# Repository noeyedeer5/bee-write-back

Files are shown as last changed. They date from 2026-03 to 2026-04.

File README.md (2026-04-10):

# Bee Write Back

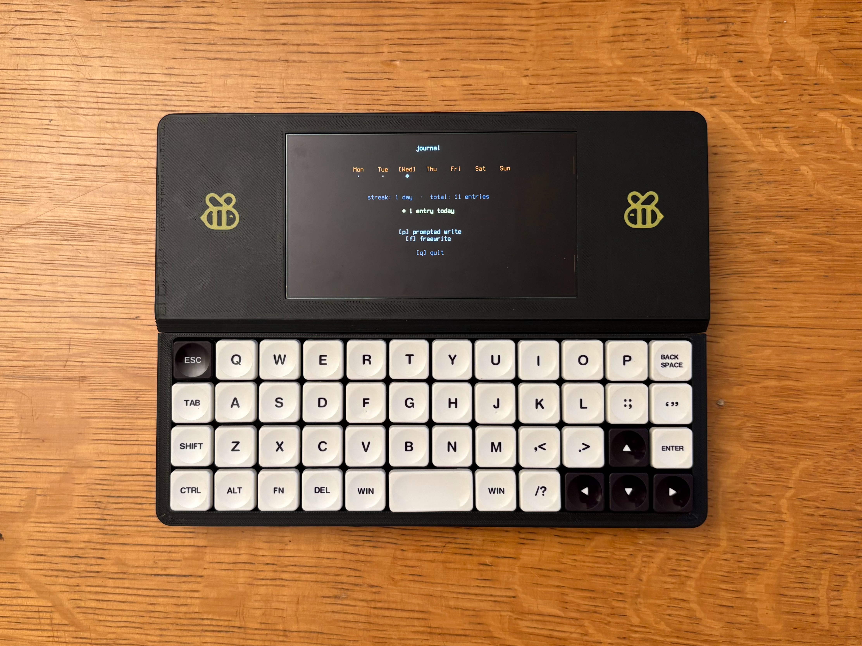
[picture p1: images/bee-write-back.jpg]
Bee Write Back WriterDeck


## Table of Contents

- [Introduction](#introduction)
- [Build Guide](#build-guide)
- [Hardware](#hardware)
- [Software](#software)
- [Cost](#cost)

## Introduction

I struggled to fall alseep easily for a while, and after being recommended journaling I found that it helped me immensely. The one catch was that I didn't like writing in a physical journal, since I would be greeted by all of my previous entries and all the emotions would come flooding back.

To solve this problem, I created a simple Raspberry Pi based journal, which I could use each night, entering in the chaos of the day, locking it away once I was done. After creating this, I found that the form factor of the writerdeck was really fun to use, and began developing more apps and functions, including a simple Claude chat client.

## Build Guide

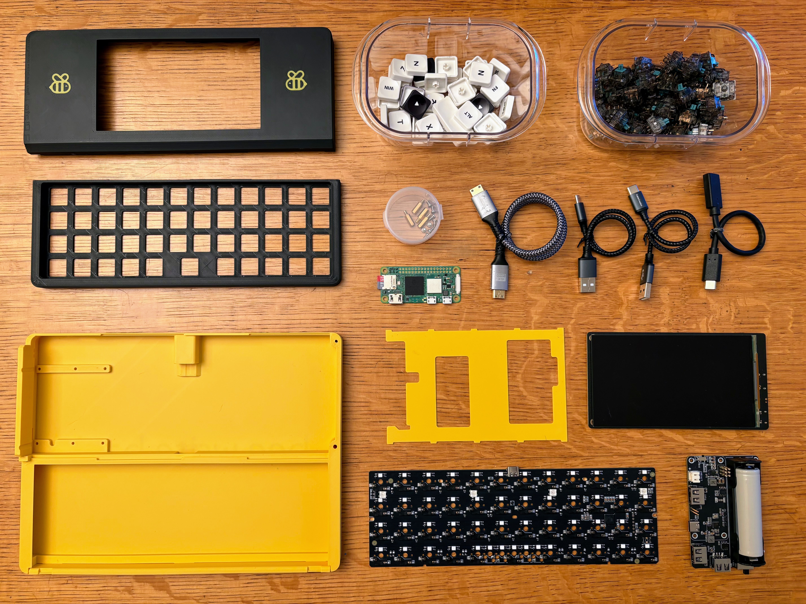
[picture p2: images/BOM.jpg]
Bee Write Back Components

  
You can view the PDF [here](Hardware/Bee%20Write%20Back%20Build%20Guide.pdf)  
Or the assembly video [here](https://youtu.be/JutsTp7yeNU)  
And when you're ready to print, check out the print profile [here](https://makerworld.com/en/models/2643352-bee-write-back-diy-writerdeck#profileId-2921008)  
  
P.S. if you're curious, try spinning around the 3D model [here](https://cad.onshape.com/documents/e6482d1ab00cb5a2719e37b7/w/38d6de8130338c05d74e4ecf/e/8865c15cb975933cc3691846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). Onshape is free, and I highly encourage taking a look at the model in 3D!

## Hardware

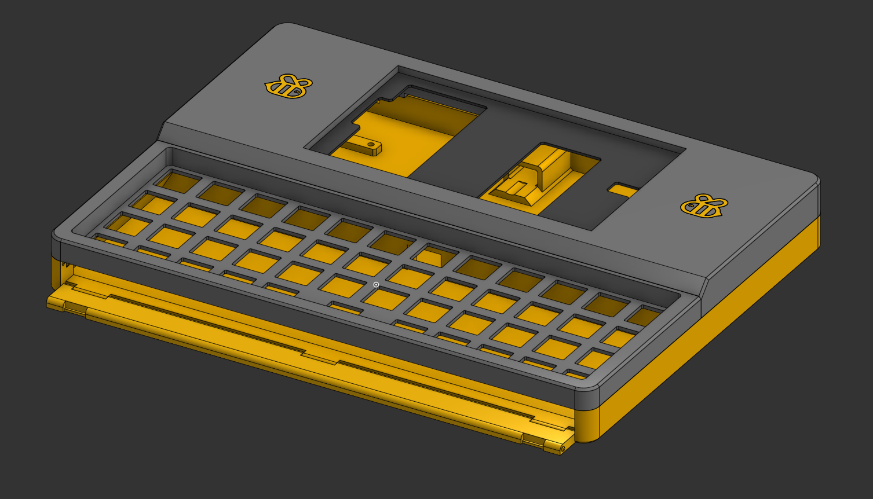
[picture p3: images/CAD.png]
CAD


You can find STEP and STL files available in the [CAD](Hardware/CAD) directory

If you want to 3D print this, you can find the STLs and 3MF files in the [Print](Hardware/CAD/Print) directory.

Since the faceplate and base utilizes multicolor printing, I have included a 3MF file. If you don't have access to multicolor printing or just want a blank faceplate, the regular STL will work. I printed my deck out of PLA, but PETG would also work.

## Software

I have included the two scripts that I vibe coded (I know it's lazy, but I have a background as a mechanical engineer, so programming is not my strong suit).

My current setup revolves around using 3 virtual terminals:
1. Standard terminal
2. Claude chat
3. Journal

In the Software folder, you will also find my .bashrc and .bashprofile file, which contain small tweaks to make switching virtual terminals as easy as possible.

## Cost

For more a more detailed breakdown of the cost for each variant, please reference the individual BOMs in their respective directory. Below are the rough totals for each variant. Screws and filament are not included in the total cost.

**TOTAL COST: $200**

(This number does not include shipping, taxes and/or tariffs)

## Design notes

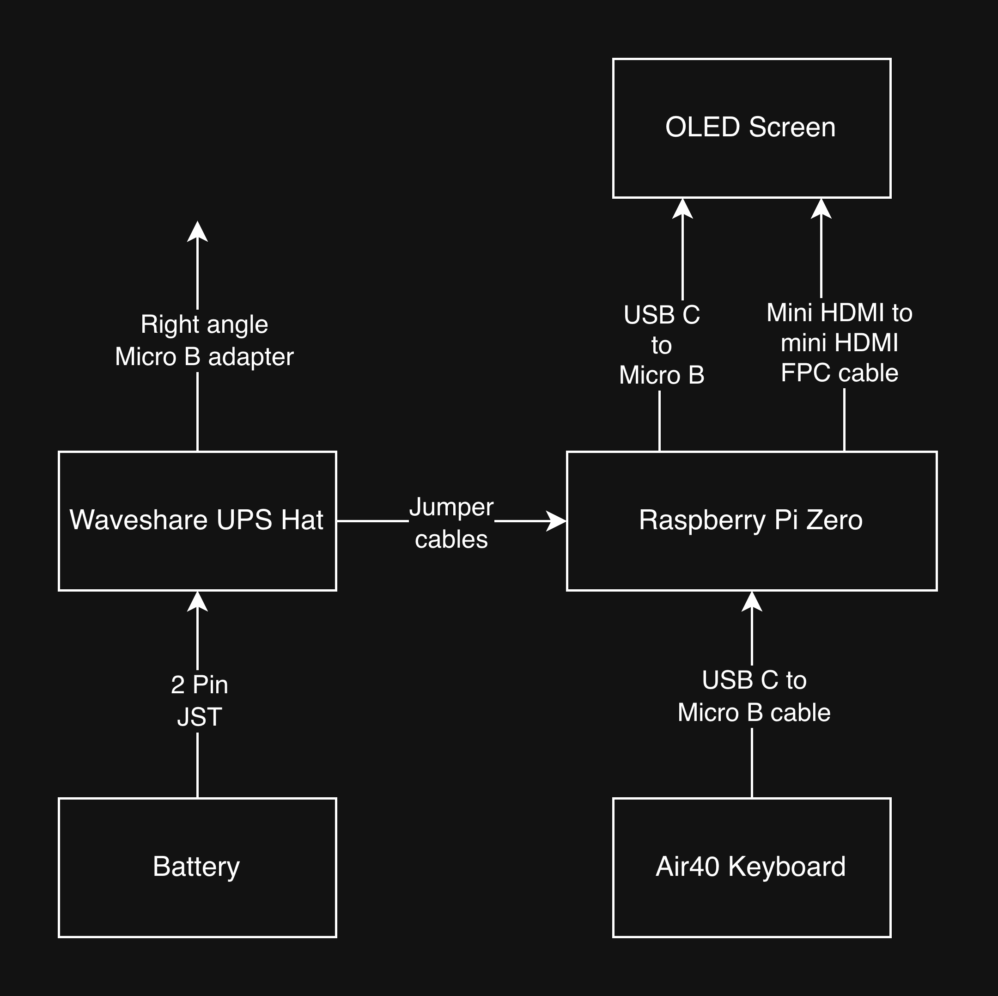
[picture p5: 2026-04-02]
images/block_OG.png

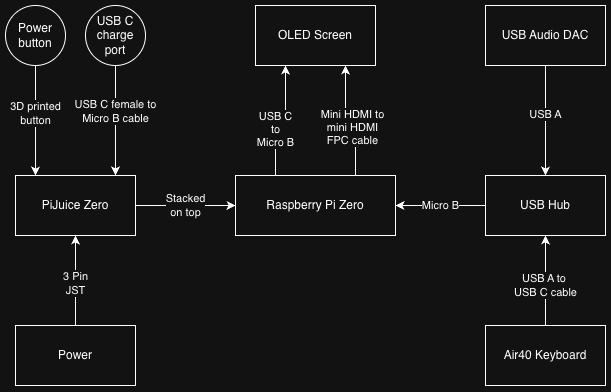
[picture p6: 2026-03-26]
images/block.png

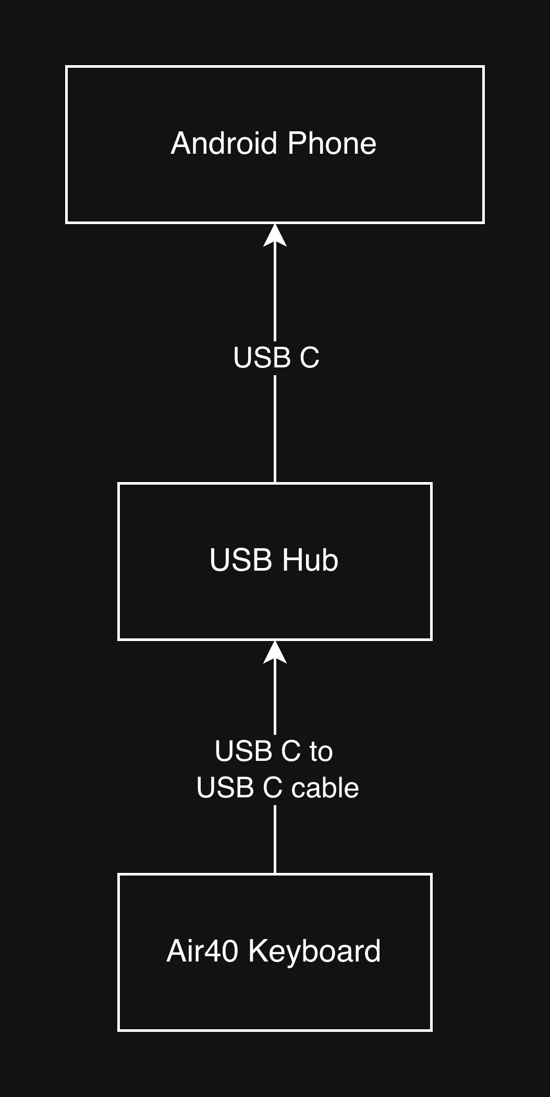
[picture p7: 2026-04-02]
images/block_AOSP.png

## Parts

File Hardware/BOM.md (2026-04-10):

| Part | Qty | Cost | Link | Notes |
|-----|-----|---|---|---|
| Raspberry Pi Zero 2 W | 1 | $20 | [raspberrypi](https://www.raspberrypi.com/products/raspberry-pi-zero-2-w/) | Without headers |
| 5.5" AMOLED Screen | 1 | $45 | [aliexpress](https://www.aliexpress.us/item/3256805978359959.html?channel=twinner) | |
| UPS and Hub Pi Hat | 1 | $25 | [amazon](https://a.co/d/0dS5rs5b) | |
| 18650 battery | 1 | $2-5 | [various](http://batteries.parametrek.com/index.html?size=18650) | |
| Air40 Keyboard PCB | 1 | $39 | [ymdk](https://ymdkey.com/products/ymd40-air40-rgb-hot-swap-pcb?variant=41586586779709) | Only PCB |
| Keyboard Switches | 48 | $20 | [ymdk](https://ymdkey.com/collections/gateron-switches) | Cherry MX footprint |
| Keycaps | 48 | $20 | [ymdk](https://ymdkey.com/collections/dsa) | DSA or XDA profile |
| USB A to C Cable | 1 | $8 | [amazon](https://a.co/d/02yecqgL) | 0.8FT 2-Pack|
| Mini to mini HDMI Cable | 1 | $10 | [amazon](https://a.co/d/08mENb0Y) | 0.3M variant |
| USB C Extender | 1 | $7 | [amazon](https://a.co/d/05VpJQLo) | Straight version |
|**Total**| | **$200** |

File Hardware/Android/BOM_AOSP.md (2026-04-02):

| Part | Qty | Cost | Link | Notes |
|-----|-----|---|---|---|
| Air40 Keyboard PCB | 1 | $35-$45 | [aliexpress](https://www.aliexpress.us/item/3256805656168067.html?channel=twinner) | | 
| Keyboard Switches | 47 | $10-$30 | [hippokeys](https://hippokeys.com/) | Cherry MX style |
| Keycaps | 47 | $14 | [chosfox](https://chosfox.com/products/chosfox-geonix-rev-2-original-keycap-set) | Low-profile |
| USB C Hub | 1 | $40 | [amazon](https://a.co/d/06b0YpKR) | |
| USB C to C cable | 1 | $9 | [amazon](https://a.co/d/05bgY2vz) |

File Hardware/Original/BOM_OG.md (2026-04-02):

| Part | Qty | Cost | Link | Notes |
|-----|-----|---|---|---|
| Raspberry Pi Zero W | 1 | $20 | [raspberrypi](https://www.raspberrypi.com/products/raspberry-pi-zero-2-w/) | Without headers |
| 5.5" AMOLED Screen | 1 | $45 | [aliexpress](https://www.aliexpress.us/item/3256805978359959.html?channel=twinner) | |
| Air40 Keyboard PCB | 1 | $35-$45 | [aliexpress](https://www.aliexpress.us/item/3256805656168067.html?channel=twinner) | | 
| UPS Hat | 1 | $25 | [waveshare](https://www.waveshare.com/ups-hat-c.htm) | |
| Keyboard Switches | 47 | ~$20 | [hippokeys](https://hippokeys.com/) | Cherry MX style |
| Keycaps | 47 | $14 | [chosfox](https://chosfox.com/products/chosfox-geonix-rev-2-original-keycap-set) | Low-profile  |
| Right angle USB C Adapter | 1 | $9 | [amazon](https://a.co/d/0iD8tdOh) | **Right** variant |
| USB C to Micro B Cable | 2 | $8 | [amazon](https://a.co/d/02apOZqa) | 1ft variant |
| FPC Mini HDMI to HDMI Cable | 1 | $9 | [amazon](https://a.co/d/05EBCFm5) | 0.2M variant |
| FPC Mini HDMI connector | 1 | $7 | [amazon](https://a.co/d/0dyc08eN) | Mini HDMI male straight |
|**Total** | |**$220**|

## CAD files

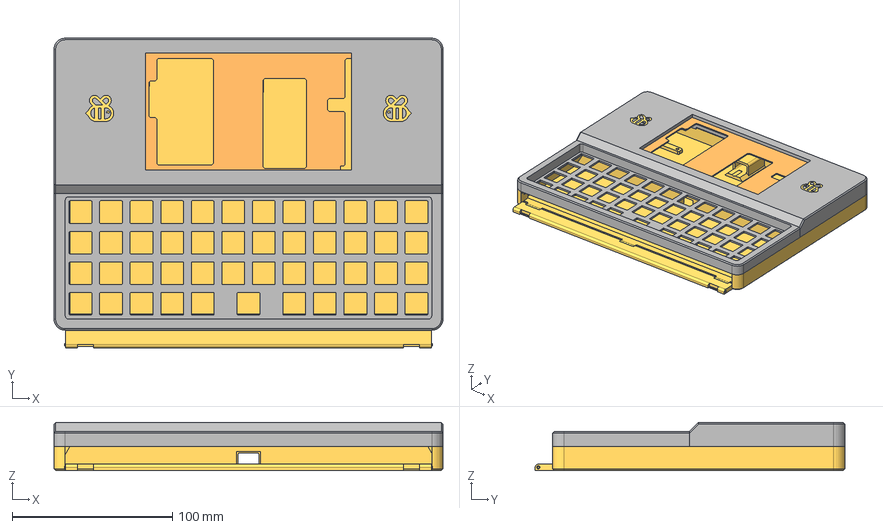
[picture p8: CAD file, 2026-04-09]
Hardware/CAD/bee-write-back.step
242.6 x 193.2 x 30.0 mm

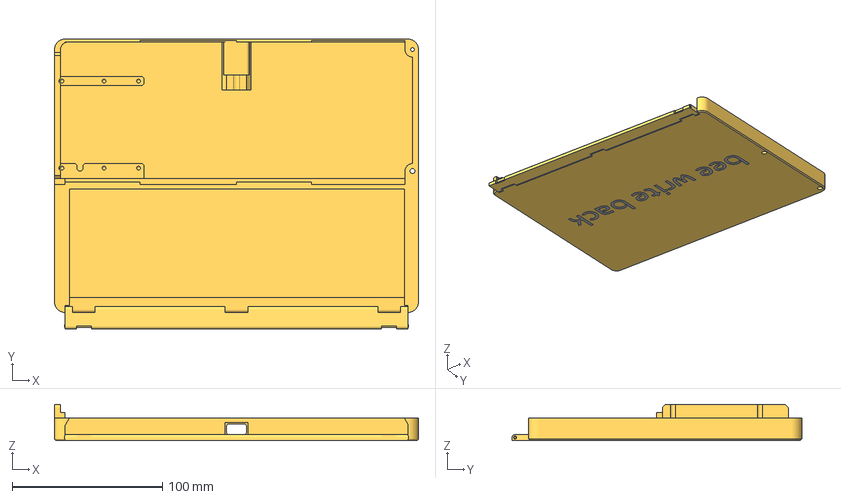
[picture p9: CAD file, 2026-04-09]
Hardware/CAD/Print/base.3mf
242.6 x 193.2 x 24.0 mm

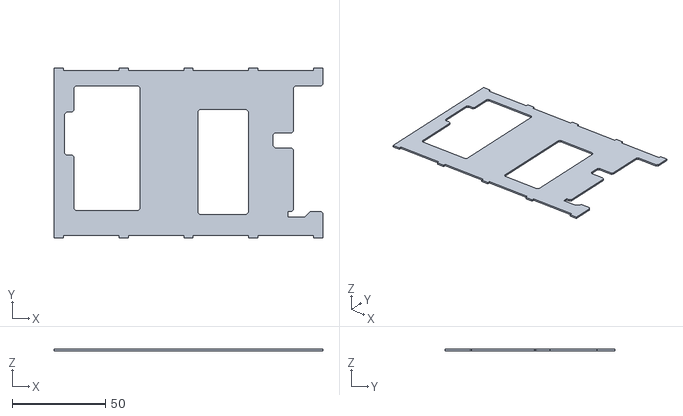
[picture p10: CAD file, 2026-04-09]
Hardware/CAD/Print/screen-retainer.stl
143.9 x 91.0 x 1.00

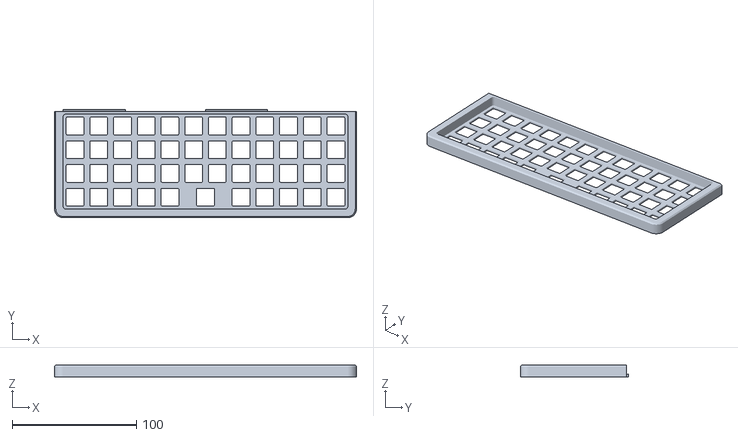
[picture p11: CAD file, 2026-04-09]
Hardware/CAD/Print/keyboard.stl
242.6 x 87.1 x 9.50

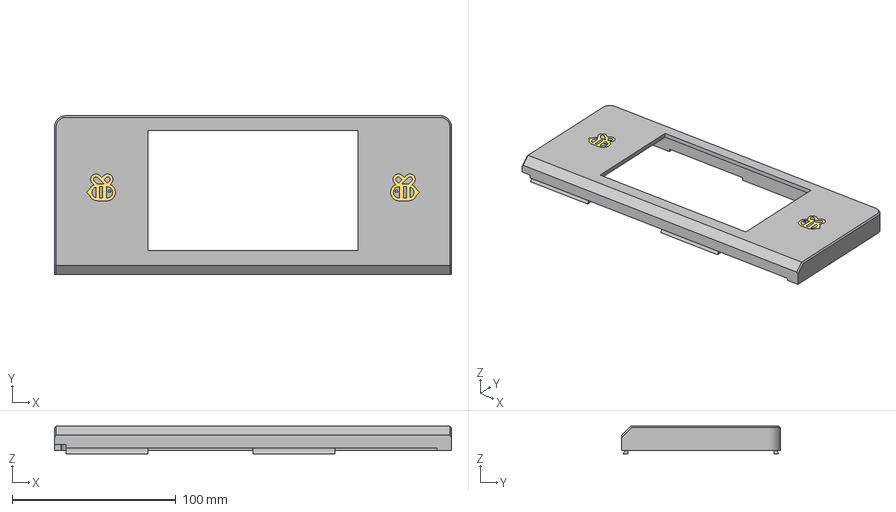
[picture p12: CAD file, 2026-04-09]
Hardware/CAD/Print/screen.3mf
242.6 x 97.0 x 17.0 mm

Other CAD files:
Hardware/CAD/Print/base.stl
Hardware/CAD/Print/screen.stl

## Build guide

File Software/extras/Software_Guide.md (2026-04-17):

# Writerdeck

## Setup

### Prerequisites

- Raspberry Pi Zero W (or any Pi) running Raspberry Pi OS Lite
- Python 3.9+
- An [Anthropic API key](https://console.anthropic.com/) (for claude-chat)

### Flashing Pi OS Lite

1. Download [Raspberry Pi Imager](https://www.raspberrypi.com/software/) on your computer
2. Insert your microSD card and open the Imager
3. Choose **Raspberry Pi Zero** as the device
4. Choose **Raspberry Pi OS Lite (64-bit)** — the version with no desktop environment
5. Write the image to the SD card
6. Insert the SD card into the Pi, connect a keyboard and power, and boot
7. From your computer, verify SSH works: `ssh youruser@yourhostname.local`

### QMK Keyboard Layer Mapping

1. Keyboards that run [QMK](https://docs.qmk.fm/keymap) like the Air40 can be mapped with custom keys
2. Plug the Air40 keyboard into your computer and go to [vial.rocks](vial.rocks) for mapping
2. For this 40% setup, I recommend at least 2 layers, with the second having:
    - The number row on the top (QWER...)
    - The function keys on the second row (ASDF...)
3. The rest is up to your taste and you can customize however you like

### Installation

```bash
# Install the API dependency
pip install anthropic --break-system-packages
```

```bash
# Clone the repo (although all we need are the scripts)
git clone https://github.com/shmimel/bee-write-back.git
```

```bash
# Navigate to scripts directory
cd bee-write-back/Software/scripts
```

```bash
# Copy scripts to home directory
cp writerdeck.py journal.py claude-chat.py splash.py ~/
```

```bash
# Create working directories
mkdir -p ~/documents ~/journal ~/scripts ~/conversations/sessions
```

### System Configuration

#### Auto-login (repeat for tty1, tty2, tty3)

Creates a systemd override that logs in automatically on each virtual console, skipping the login prompt and all system messages.

```bash
sudo mkdir -p /etc/systemd/system/getty@tty1.service.d
sudo tee /etc/systemd/system/getty@tty1.service.d/override.conf << 'EOF'
[Service]
ExecStart=
ExecStart=-/sbin/agetty --autologin YOUR_USER --skip-login --noclear --noissue --nohostname %I $TERM
EOF
sudo systemctl daemon-reload
```

#### Suppress login messages

Removes the default Debian banner, IP address display, and "Last login" line so boot goes straight to a clean screen.

```bash
sudo truncate -s 0 /etc/issue        # removes "Debian GNU/Linux..." banner
sudo rm -f /etc/issue.d/*            # removes "My IP address is..." line
touch ~/.hushlogin                    # suppresses MOTD and "Last login" message
```

#### ~/.bash_profile

This file runs once when a login shell starts on each TTY. Add each section to the ~/.bash_profile file:

Set up clean login screen
```bash
clear
```

Load .bashrc properly
```bash
if [ -f ~/.bashrc ]; then
    source ~/.bashrc
fi
```

Set up 3 virtual terminals
```bash
if [ "$(tty)" = "/dev/tty1" ] && [ -z "$SCRIPT_RUNNING" ]; then
    export SCRIPT_RUNNING=1
    exec script -q -f ~/.tty1.log
fi
```

Launch app automatically when terminal is switched to
```bash
case "$(tty)" in
    /dev/tty2)
        python3 ~/splash.py "claude-chat" "starting..."
        python3 ~/claude-chat.py
        ;;
    /dev/tty3)
        python3 ~/splash.py "journal" "starting..."
        python3 ~/journal.py
        ;;
esac
```

#### ~/.bashrc

This file runs for every shell session (both login and interactive). It sets up the environment and tty1 helper commands. Add each block to ~/.bashrc

Python environment path
```bash
# Add pip-installed scripts to PATH
export PATH="$HOME/.local/bin:$PATH"
```
Anthropic API key
```bash
# Anthropic API key for claude-chat
export ANTHROPIC_API_KEY="sk-ant-your-key-here"
```
Add in temporary code block execution from claude-chat client
```bash
# ── claude-chat tty1 integration ──

# Execute the last code block sent from claude-chat via /cmd
run() {
    if [ -f ~/.lastcmd ]; then
        echo "── running ~/.lastcmd ──"
        bash ~/.lastcmd
        rm -f ~/.lastcmd.ts
        export __last_cmd_ts="0"
    else
        echo "no command ready"
    fi
}

# Preview the command before running it
grab() {
    if [ -f ~/.lastcmd ]; then
        cat ~/.lastcmd
    else
        echo "no command ready"
    fi
}

# Prompt indicator: shows [cmd] when a new command is waiting from claude-chat
__cmd_check() {
    if [ -f ~/.lastcmd.ts ]; then
        local ts=$(cat ~/.lastcmd.ts 2>/dev/null)
        local last=${__last_cmd_ts:-0}
        if [ "$ts" != "$last" ]; then
            echo -n " [cmd]"
            export __last_cmd_ts="$ts"
        fi
    fi
}
```

### context.txt

Create `~/context.txt` to give claude-chat persistent context about your setup and preferences. This is loaded into every conversation automatically. The chat client also builds a lightweight index of your recent session titles so Claude is aware of past conversations without loading their full content.

```
I'm using a dedicated writing device built with a Raspberry Pi Zero.
My device has three TTYs: shell, claude-chat, and journal.
I prefer terminal-friendly responses with minimal markdown.
```

## File Structure

```
~/
├── writerdeck.py          # Text editor
├── journal.py             # Journal app
├── claude-chat.py         # AI chat client
├── splash.py              # Boot splash screen
├── context.txt            # Persistent AI context
├── documents/             # Writerdeck files
│   └── .cursors.json      # Saved cursor positions
├── journal/               # Journal entries
│   └── 2026-03-27_143022.txt
├── scripts/               # Exported scripts from chat
├── conversations/
│   └── sessions/          # Chat session data (JSON)
├── .tty1.log              # Terminal output log
├── .lastcmd               # Last command from /cmd
└── .lastcmd.ts            # Command notification timestamp
```

## Software

### writerdeck.py — Text Editor

A minimal curses-based text editor for focused writing.

- Full-screen editor with file browser (`~/documents/`)
- Word wrapping (visual only, preserves original line breaks)
- Cursor position remembered between sessions
- Auto-save on every quit
- Word count and position display

**Keys:** `Ctrl+W` / `Ctrl+Q` / `Esc` save and close. `Ctrl+S` save. `Ctrl+G` go to line.

### journal.py — Daily Journal

A write-once journal with daily prompts and progress tracking.

- Weekly tracker showing completed days with streak counter
- 561 writing prompts (sourced from [Day One's prompt library](https://dayoneapp.com/blog/journal-prompts/))
- Prompted write or freewrite modes
- Browse and read past entries (read-only)
- Entries saved as plain text to `~/journal/`

**Keys:** `p` prompted write. `f` freewrite. `v` view past entries. `Ctrl+W` finish and save.

### claude-chat.py — AI Chat Client

A pager-style chat client for the Anthropic API with session management and code export.

- Session picker with AI-generated titles
- Full conversation persistence and resume
- Animated loading screen while waiting for responses
- Markdown rendering with numbered code blocks
- Collapsible long prompts
- Scrollable multi-line input
- Auto-loaded context from `~/context.txt` with cross-session awareness

**Commands:**

| Command | Description |
|---|---|
| `/save [file] [#]` | Save code block to `~/scripts/` |
| `/cmd [#]` | Send code block to tty1 |
| `/blocks` | List all code blocks in response |
| `/upload <path>` | Upload file or directory to conversation |
| `/term` | Share recent tty1 output with Claude |
| `/model [name]` | Show or switch AI model |
| `/quit` | Save session and exit |

**Navigation:** `↑↓` scroll. `←→` previous/next exchange. `e` expand/collapse prompt. `g/G` top/bottom. `h` help. `i` start typing. `q` quit.

**tty1 Integration:** Code blocks sent with `/cmd` can be previewed with `grab` and executed with `run` on tty1. A `[cmd]` indicator appears in the shell prompt when a command is waiting.

### splash.py — Boot Splash

Centered loading screen displayed while apps start on tty2 and tty3.

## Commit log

2026-04-02 Add detailed BOM for hardware components
    Added detailed BOM with parts, quantities, costs, and links for hardware components.
2026-04-09 Added build guide PDF and other small changes
    [base.3mf, base.stl, bee-write-back.step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]
2026-04-10 BOM typo fix
